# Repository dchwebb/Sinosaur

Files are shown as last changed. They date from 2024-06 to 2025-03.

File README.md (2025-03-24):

# Sinosaur

## Overview

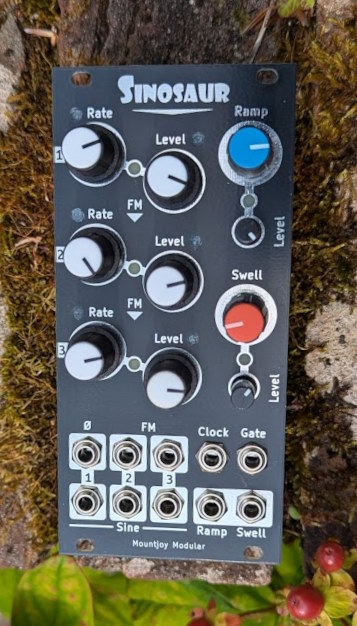
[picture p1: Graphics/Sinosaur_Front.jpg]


Sinosaur is an LFO and simple envelope generator for use in a Eurorack modular synthesiser. Two envelopes are available: a ramp and a swell, each with a speed and a level control. Each of the sine waves has a rate and level control both of which can be controlled with either envelope.

Sine 1 has a normal output and a phase inverted output. Sines 2 and 3 have a normal output and an FM output, which is derived from the preceding sine wave. Clicking the sine wave's rate or level potentiometer switches the ramp or swell envelopes on for that control. An LED cycles between blue (ramp control), red (swell control) or off to show envelope control.

If a sine's rate is controlled by the ramp, then the rate of the sine wave will increase from its slowest rate up to the rate selected by the potentiometer. In swell mode the rate will increase to the potentiometer level and then fade back to its slowest rate. Envelope control over the sine wave's level works similarly.

A gate input controls the start of the ramp and swell envelopes. The ramp will increase to its selected level whilst the gate is high and then rapidly decrease to zero. The swell rise and fall times are jointly set by the swell potentiometer, with the fall time twice as slow as the rise time.

A clock input is also available to limit the sine wave rates to multiples and divisions of the clock. Changing the rate (either with the potentiometer or envelope) selects from 8x, 4x, 2x, 1, 0.5x and 0.25x the clock rate.

## Outputs

Outputs range from 0V to 6.6V. The level control of the sine waves amplifies from 0v up to a 0V - 6.6V level (ie unipolar rather than bipolar around a central level). The inverted sine's level is 6.6V when the level control is at zero and increases to a maximum swing of 6.6V to 0V.

The levels of the envlopes and sine waves is displayed using LEDs (blue for ramp, orange for swell and white for sine waves).

## Technical

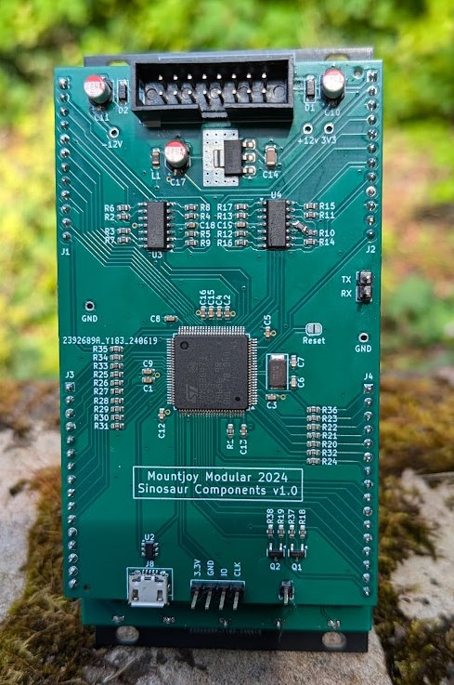
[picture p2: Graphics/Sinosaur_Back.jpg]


The module is based around an STM32G473 microcontroller, clocked at 170MHz. The various sine wave and envelopes are all generated internally by one of the microcontroller's seven 12 bit DACs.

TL074 quad op-amps are used to amplify (and/or phase invert) the outputs from 3.3V to 6.6V at maximum.

The level LEDs are controlled by PWM by hardware Timer channels on the microcontroller. Clock and Gate inputs are protected with transistor voltage limiters.

The module is designed to support USB input but this is unused at present.

[Components schematic](Hardware/Sinosaur_Components.pdf)

[Controls schematic](Hardware/Sinosaur_Controls.pdf)

## Power

Power is supplied via a 3.3V LDO regulator.

- +12V current draw: 90 mA
- -12V Current draw: 14 mA

## Errata

The inverted output of sine 1 will produce a -6.6V to 0V signal. As detailed on the component schematic a resistor is added to mix in the -12V signal raising the output to 0 - 6.6N.

This is still not ideal as at a zero level the inverted output is at 6.6V. No obvious solution available other than adding an additional DAC.

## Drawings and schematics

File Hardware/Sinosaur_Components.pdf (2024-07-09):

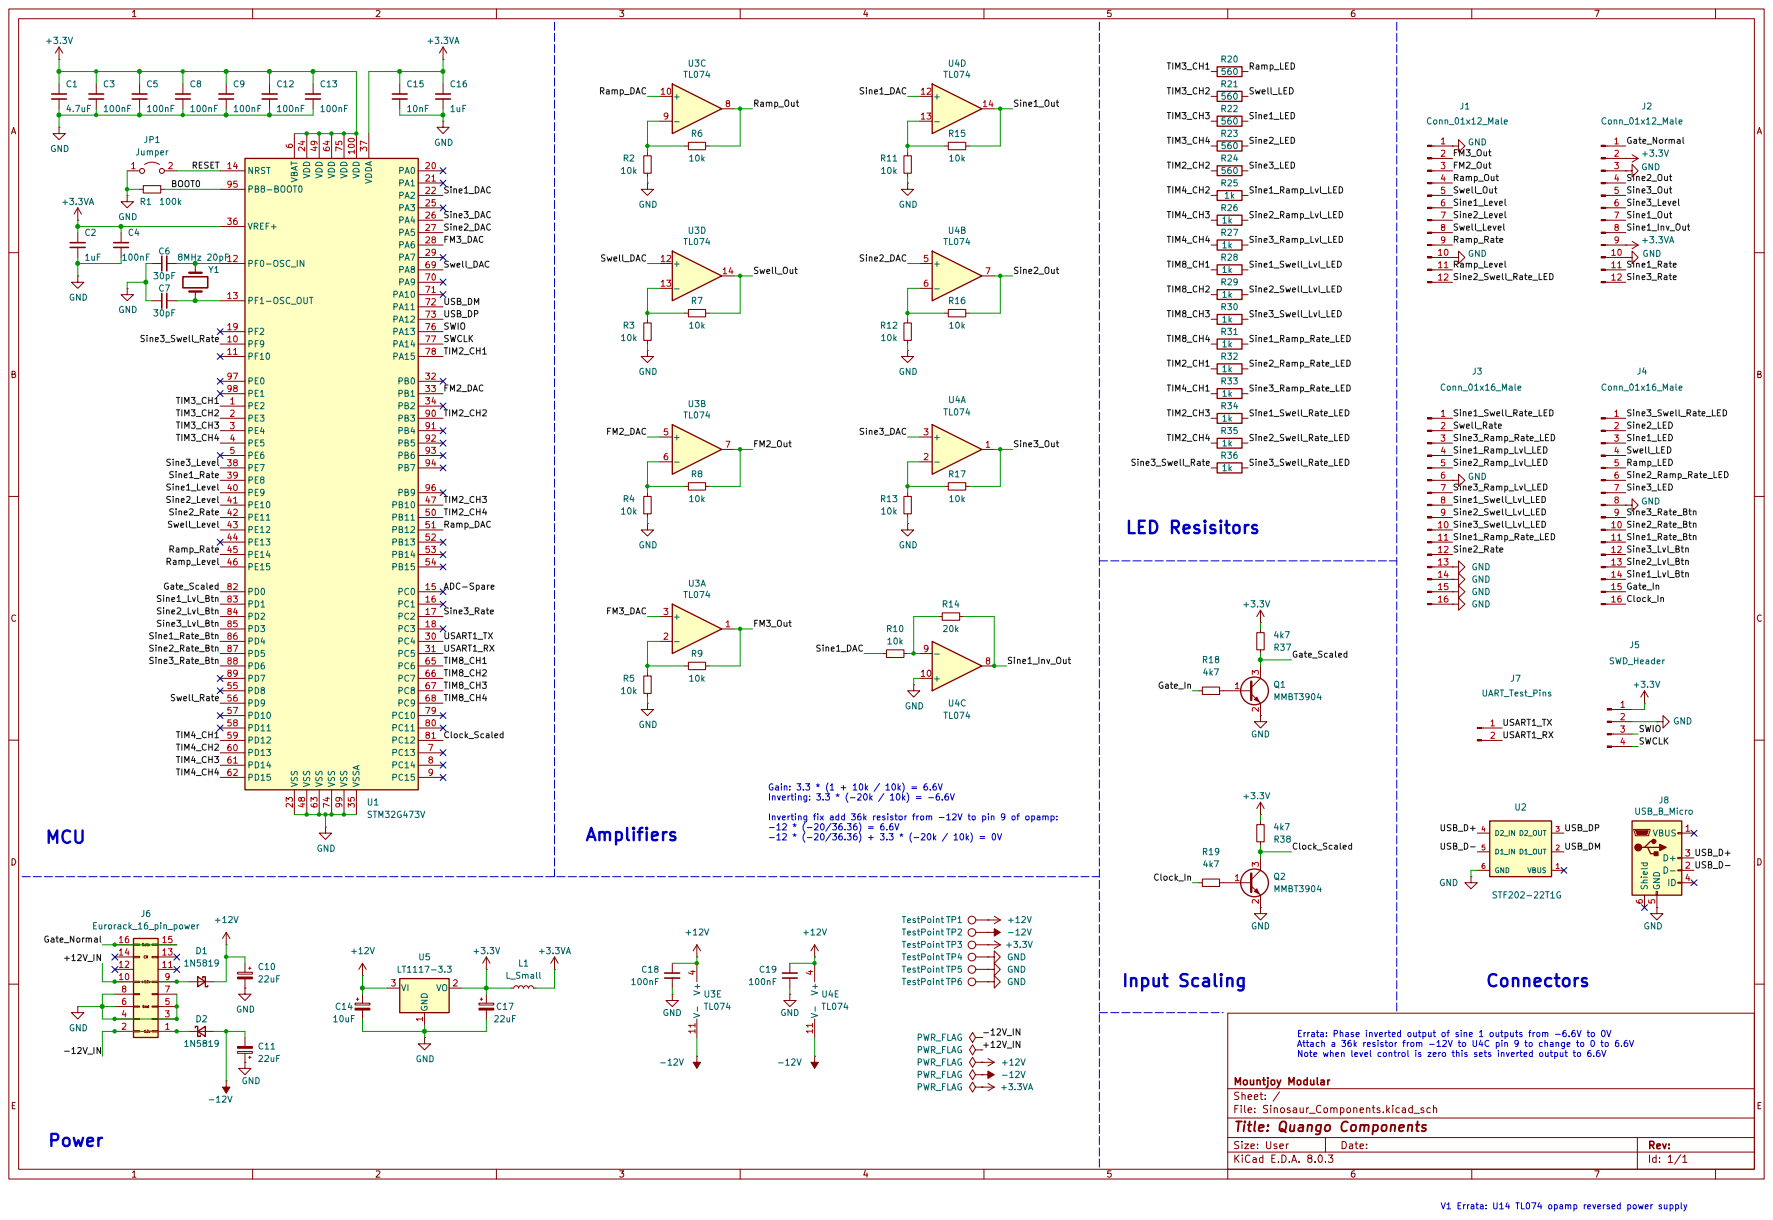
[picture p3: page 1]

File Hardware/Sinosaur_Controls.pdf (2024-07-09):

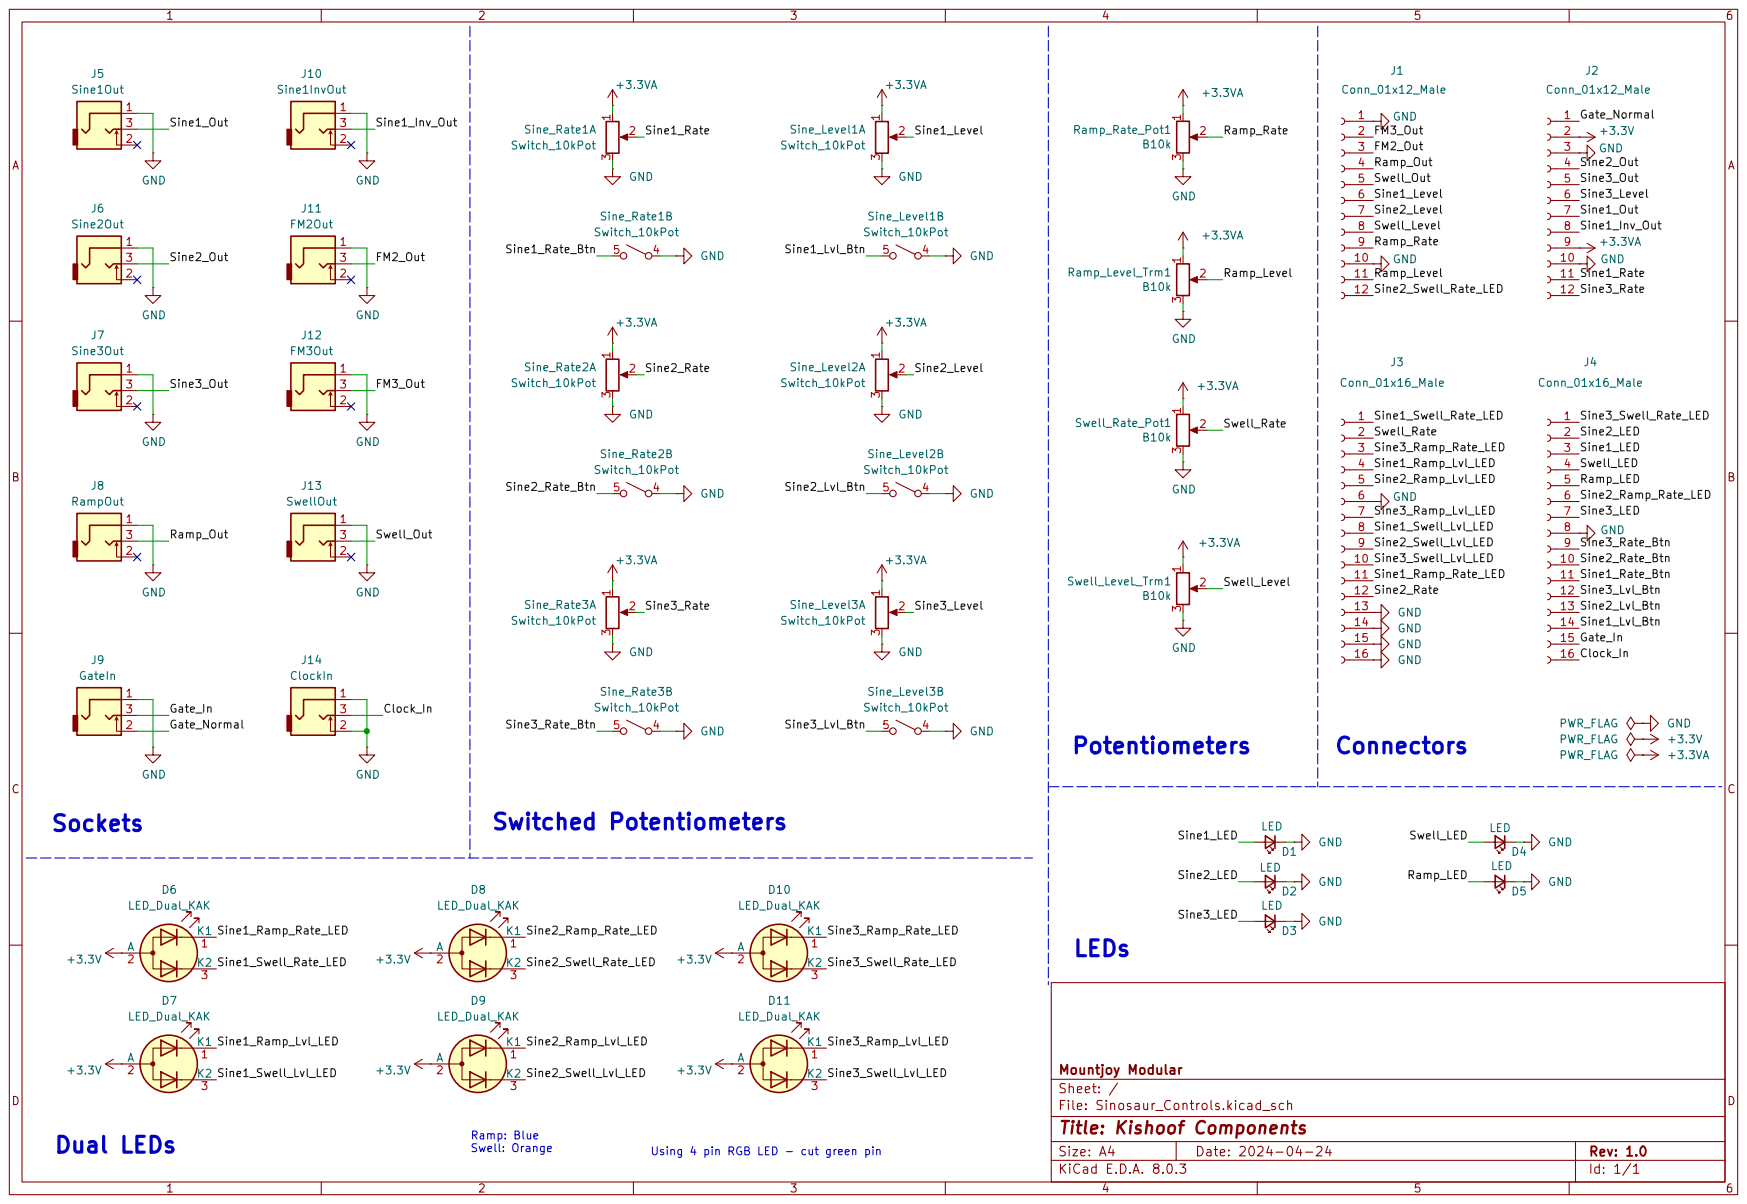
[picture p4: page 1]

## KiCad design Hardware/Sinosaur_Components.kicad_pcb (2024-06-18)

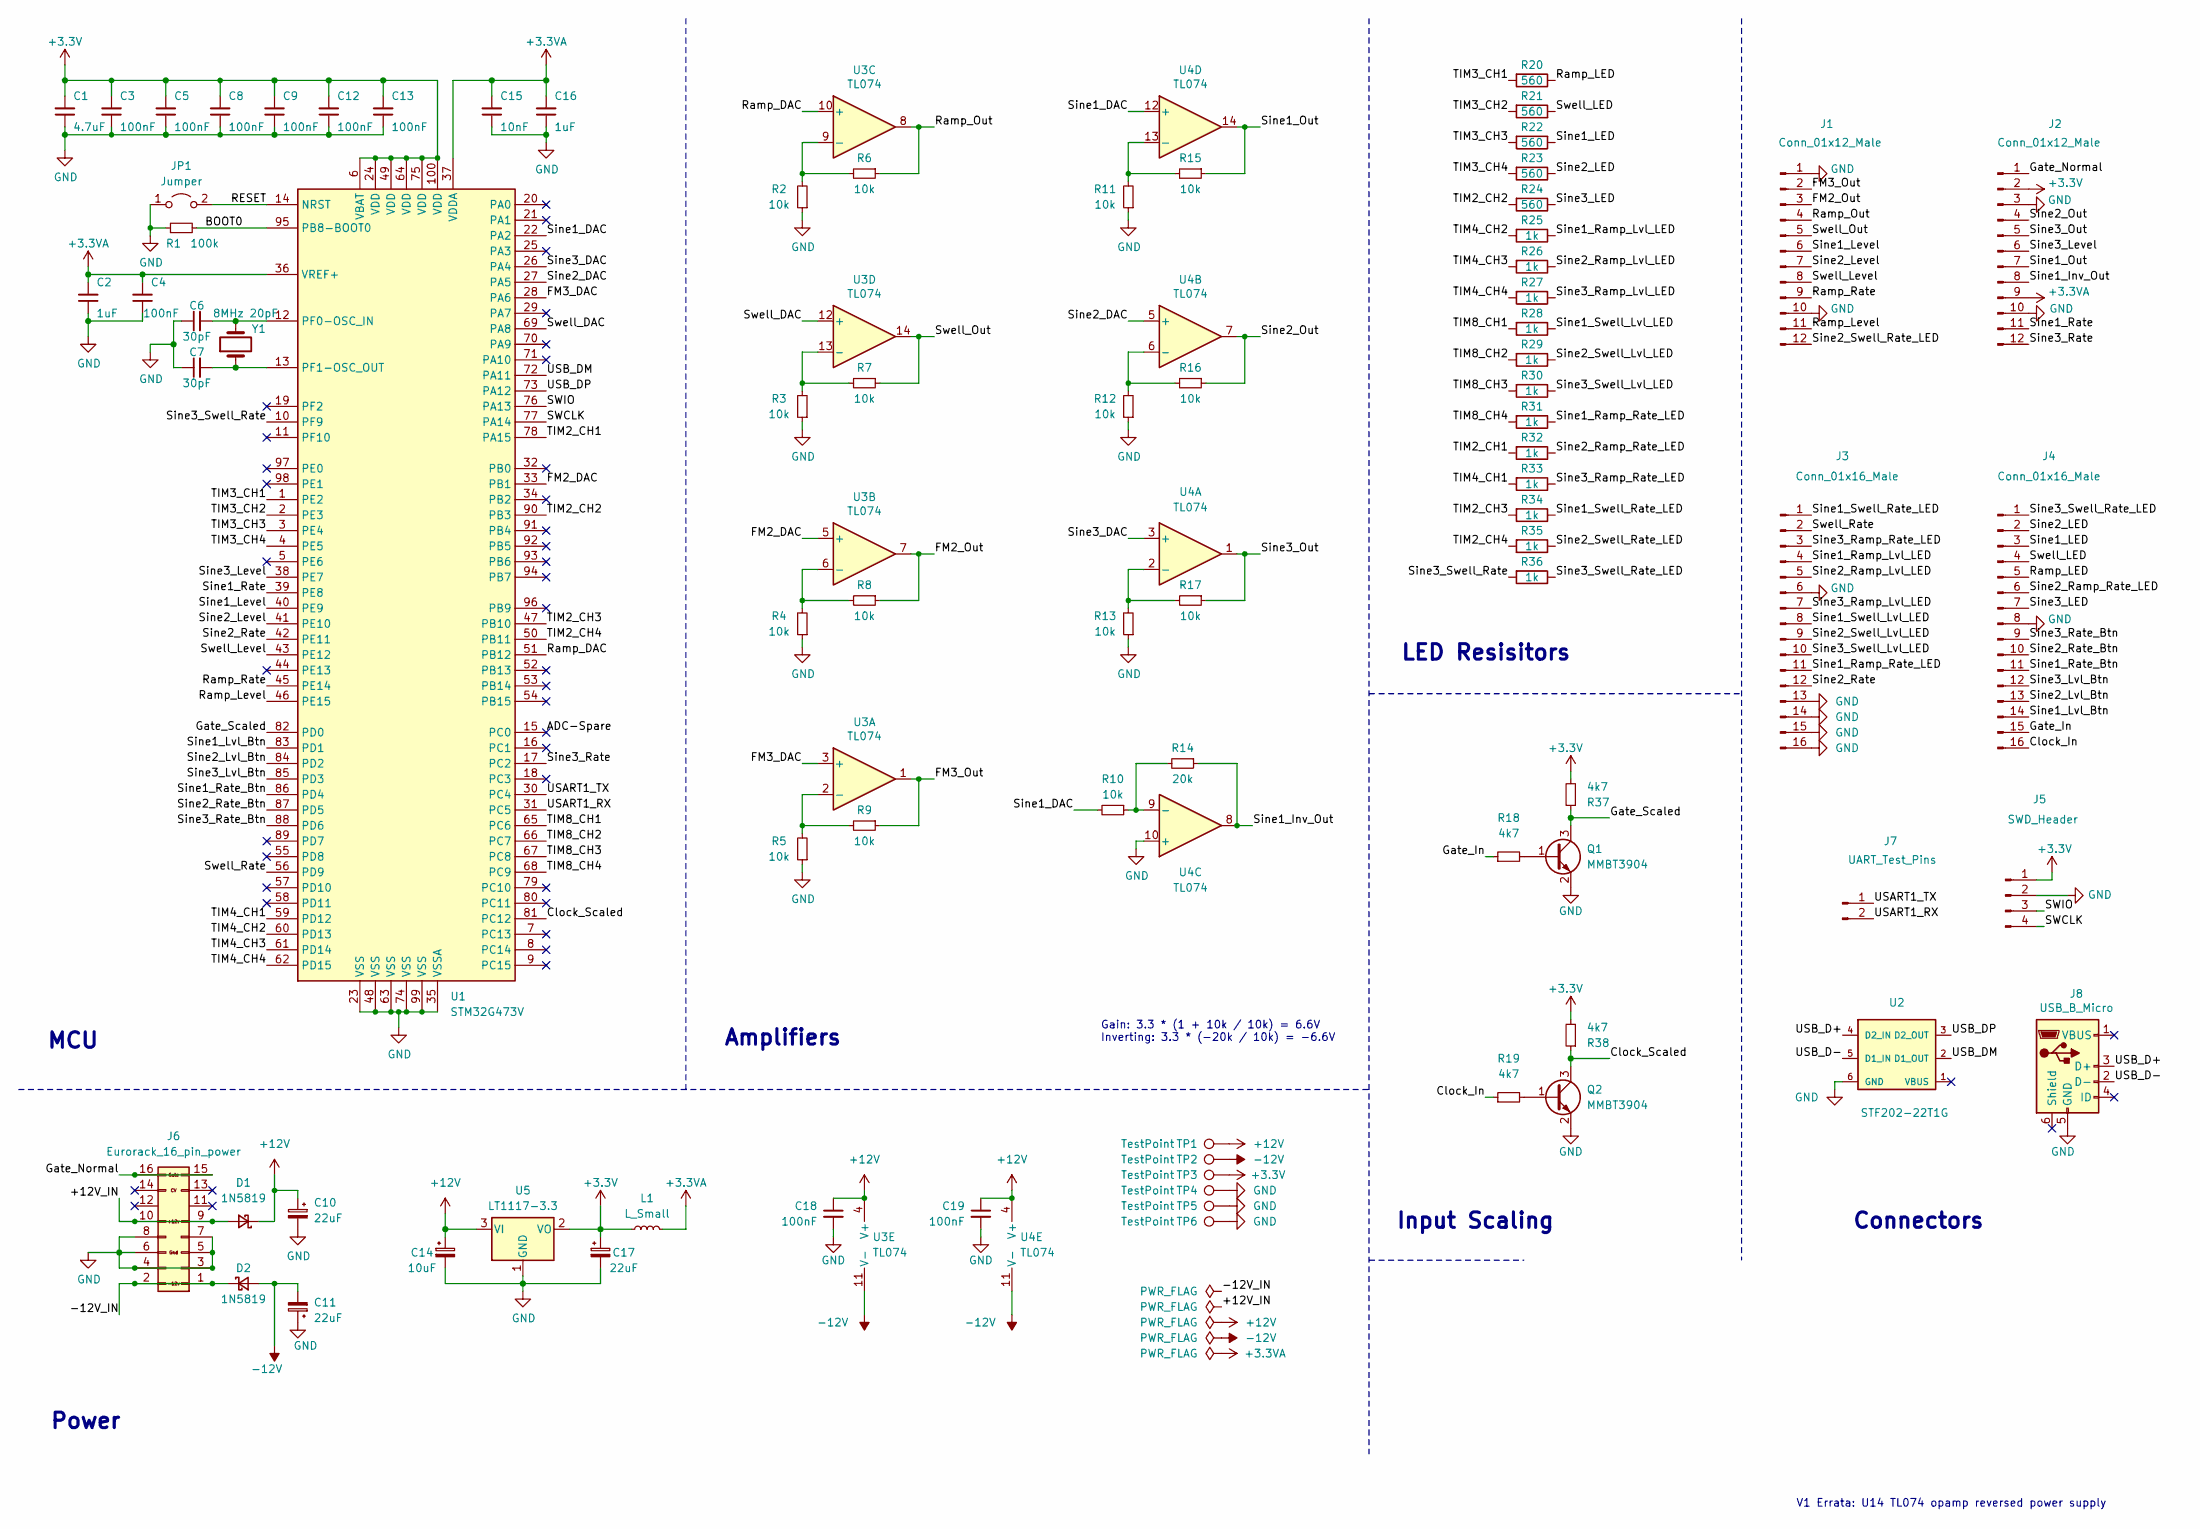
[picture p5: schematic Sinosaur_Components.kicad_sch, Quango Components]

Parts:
C1: 4.7uF; C_0603_1608Metric; Part_Number C19666
C2, C16: 1uF; C_0603_1608Metric; Part_Number C15849
C3, C4, C5, C8, C9, C12, C13: 100nF; C_0603_1608Metric; Part_Number C14663
C6, C7: 30pF; C_0603_1608Metric; Part_Number C22397
C10, C11, C17: 22uF; CP_Elec_4x5.8
C14: 10uF; C_1206_3216Metric
C15: 10nF; C_0603_1608Metric; Part_Number C57112
C18, C19: 100nF; C_0603_1608Metric; Part_Number C23630
D1, D2: 1N5819; D_SOD-123
J1, J2: Conn_01x12_Male; PinHeader_1x12_P2.54mm_Vertical
J3, J4: Conn_01x16_Male; PinHeader_1x16_P2.54mm_Vertical
J5: SWD_Header; SWD_header
J6: Eurorack_16_pin_power; Eurorack_16_pin_header
J7: UART_Test_Pins; PinHeader_1x02_P2.54mm_Vertical
J8: USB_B_Micro; USB_Micro-B_Amphenol
JP1: Jumper; SolderJumper-2_P1.3mm_Open_RoundedPad1.0x1.5mm
L1: L_Small; L_0805_2012Metric_Pad1.05x1.20mm_HandSolder; Part_Number C1046
Q1, Q2: MMBT3904; SOT-23; Part_Number C20526
R1: 100k; R_0603_1608Metric; Part_Number C25803
R2, R3, R4, R5, R6, R7, R8, R9, R10, R11, R12, R13, R15, R16, R17: 10k; R_0603_1608Metric
R14: 20k; R_0603_1608Metric
R18, R19, R37, R38: 4k7; R_0603_1608Metric; Part_Number C23162
R20, R21, R22, R23, R24: 560; R_0603_1608Metric; Part_Number C23212
R25, R26, R27, R28, R29, R30, R31, R32, R33, R34, R35, R36: 1k; R_0603_1608Metric; Part_Number C23212
TP1, TP2, TP3, TP4, TP5, TP6: TestPoint; 1mm_Test_Point
U1: STM32G473V; LQFP-100_14x14mm_P0.5mm
U2: STF202-22T1G
U3, U4: TL074; SOIC-14_3.9x8.7mm_P1.27mm
U5: LT1117-3.3; SOT-223-3_TabPin2
Y1: 8MHz 20pF; Crystal_SMD_0603-2Pin_6.0x3.5mm; Part_Number C115962

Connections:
+3.3V: C1.2, C3.2, C5.2, C8.2, C9.2, C12.2, C13.2, C17.1, J2.2, J5.1, L1.1, R37.2, R38.2, TP3.1, U1.6 (VBAT), U1.24 (VDD), U1.49 (VDD), U1.64 (VDD), U1.75 (VDD), U1.100 (VDD), U5.2 (VO)
+3.3VA: C2.2, C4.2, C15.2, C16.2, J2.9, L1.2, U1.36 (VREF+), U1.37 (VDDA)
+12V: C10.1, C14.1, C18.1, C19.1, D1.1 (K), TP1.1, U3.4 (V+), U4.4 (V+), U5.3 (VI)
-12V: C11.2, D2.2 (A), TP2.1, U3.11 (V-), U4.11 (V-)
/+12V_IN: D1.2 (A), J6.9, J6.10
/-12V_IN: D2.1 (K), J6.1, J6.2
/ADC-Spare: U1.15 (PC0)
/BOOT0: R1.2, U1.95 (PB8-BOOT0)
/Clock_In: J4.16, R19.1
/Clock_Scaled: Q2.3 (C), R38.1, U1.81 (PC12)
/FM2_DAC: U1.33 (PB1), U3.5 (+)
/FM2_Out: J1.3, R8.1, U3.7
/FM3_DAC: U1.28 (PA6), U3.3 (+)
/FM3_Out: J1.2, R9.1, U3.1
/Gate_In: J4.15, R18.1
/Gate_Normal: J2.1, J6.15, J6.16
/Gate_Scaled: Q1.3 (C), R37.1, U1.82 (PD0)
/RESET: JP1.2 (B), U1.14 (NRST)
/Ramp_DAC: U1.51 (PB12), U3.10 (+)
/Ramp_LED: J4.5, R20.1
/Ramp_Level: J1.11, U1.46 (PE15)
/Ramp_Out: J1.4, R6.1, U3.8
/Ramp_Rate: J1.9, U1.45 (PE14)
/SWCLK: J5.4, U1.77 (PA14)
/SWIO: J5.3, U1.76 (PA13)
/Sine1_DAC: R10.2, U1.22 (PA2), U4.12 (+)
/Sine1_Inv_Out: J2.8, R14.1, U4.8
/Sine1_LED: J4.3, R22.1
/Sine1_Level: J1.6, U1.40 (PE9)
/Sine1_Lvl_Btn: J4.14, U1.83 (PD1)
/Sine1_Out: J2.7, R15.1, U4.14
/Sine1_Ramp_Lvl_LED: J3.4, R25.1
/Sine1_Ramp_Rate_LED: J3.11, R31.1
/Sine1_Rate: J2.11, U1.39 (PE8)
/Sine1_Rate_Btn: J4.11, U1.86 (PD4)
/Sine1_Swell_Lvl_LED: J3.8, R28.1
/Sine1_Swell_Rate_LED: J3.1, R34.1
/Sine2_DAC: U1.27 (PA5), U4.5 (+)
/Sine2_LED: J4.2, R23.1
/Sine2_Level: J1.7, U1.41 (PE10)
/Sine2_Lvl_Btn: J4.13, U1.84 (PD2)
/Sine2_Out: J2.4, R16.1, U4.7
/Sine2_Ramp_Lvl_LED: J3.5, R26.1
/Sine2_Ramp_Rate_LED: J4.6, R32.1
/Sine2_Rate: J3.12, U1.42 (PE11)
/Sine2_Rate_Btn: J4.10, U1.87 (PD5)
/Sine2_Swell_Lvl_LED: J3.9, R29.1
/Sine2_Swell_Rate_LED: J1.12, R35.1
/Sine3_DAC: U1.26 (PA4), U4.3 (+)
/Sine3_LED: J4.7, R24.1
/Sine3_Level: J2.6, U1.38 (PE7)
/Sine3_Lvl_Btn: J4.12, U1.85 (PD3)
/Sine3_Out: J2.5, R17.1, U4.1
/Sine3_Ramp_Lvl_LED: J3.7, R27.1
/Sine3_Ramp_Rate_LED: J3.3, R33.1
/Sine3_Rate: J2.12, U1.17 (PC2)
/Sine3_Rate_Btn: J4.9, U1.88 (PD6)
/Sine3_Swell_Lvl_LED: J3.10, R30.1
/Sine3_Swell_Rate: R36.2, U1.10 (PF9)
/Sine3_Swell_Rate_LED: J4.1, R36.1
/Swell_DAC: U1.69 (PA8), U3.12 (+)
/Swell_LED: J4.4, R21.1
/Swell_Level: J1.8, U1.43 (PE12)
/Swell_Out: J1.5, R7.1, U3.14
/Swell_Rate: J3.2, U1.56 (PD9)
/TIM2_CH1: R32.2, U1.78 (PA15)
/TIM2_CH2: R24.2, U1.90 (PB3)
/TIM2_CH3: R34.2, U1.47 (PB10)
/TIM2_CH4: R35.2, U1.50 (PB11)
/TIM3_CH1: R20.2, U1.1 (PE2)
/TIM3_CH2: R21.2, U1.2 (PE3)
/TIM3_CH3: R22.2, U1.3 (PE4)
/TIM3_CH4: R23.2, U1.4 (PE5)
/TIM4_CH1: R33.2, U1.59 (PD12)
/TIM4_CH2: R25.2, U1.60 (PD13)
/TIM4_CH3: R26.2, U1.61 (PD14)
/TIM4_CH4: R27.2, U1.62 (PD15)
/TIM8_CH1: R28.2, U1.65 (PC6)
/TIM8_CH2: R29.2, U1.66 (PC7)
/TIM8_CH3: R30.2, U1.67 (PC8)
/TIM8_CH4: R31.2, U1.68 (PC9)
/USART1_RX: J7.2, U1.31 (PC5)
/USART1_TX: J7.1, U1.30 (PC4)
/USB_D+: J8.3 (D+), U2.4 (D2_IN)
/USB_D-: J8.2 (D-), U2.5 (D1_IN)
/USB_DM: U1.72 (PA11), U2.2 (D1_OUT)
/USB_DP: U1.73 (PA12), U2.3 (D2_OUT)
GND: C1.1, C2.1, C3.1, C4.1, C5.1, C6.1, C7.1, C8.1, C9.1, C10.2, C11.1, C12.1, C13.1, C14.2, C15.1, C16.1, C17.2, C18.2, C19.2, J1.1, J1.10, J2.3, J2.10, J3.6, J3.13, J3.14, J3.15, J3.16, J4.8, J5.2, J6.3, J6.4, J6.5, J6.6, J6.7, J6.8, J8.5 (GND), JP1.1 (A), Q1.2 (E), Q2.2 (E), R1.1, R2.1, R3.1, R4.1, R5.1, R11.1, R12.1, R13.1, TP4.1, TP5.1, TP6.1, U1.23 (VSS), U1.35 (VSSA), U1.48 (VSS), U1.63 (VSS), U1.74 (VSS), U1.99 (VSS), U2.6 (GND), U4.10 (+), U5.1 (GND)
unnamed: Q1.1 (B), R18.2
unnamed: Q2.1 (B), R19.2
unnamed: C6.2, U1.12 (PF0-OSC_IN), Y1.2
unnamed: C7.2, U1.13 (PF1-OSC_OUT), Y1.1
unnamed: R5.2, R9.2, U3.2 (-)
unnamed: R4.2, R8.2, U3.6 (-)
unnamed: R2.2, R6.2, U3.9 (-)
unnamed: R3.2, R7.2, U3.13 (-)
unnamed: R13.2, R17.2, U4.2 (-)
unnamed: R12.2, R16.2, U4.6 (-)
unnamed: R10.1, R14.2, U4.9 (-)
unnamed: R11.2, R15.2, U4.13 (-)

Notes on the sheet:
Connectors
Power
V1 Errata: U14 TL074 opamp reversed power supply
MCU
Gain: 3.3 * (1 + 10k / 10k) = 6.6V Inverting: 3.3 * (-20k / 10k) = -6.6V
Input Scaling
Amplifiers
LED Resisitors

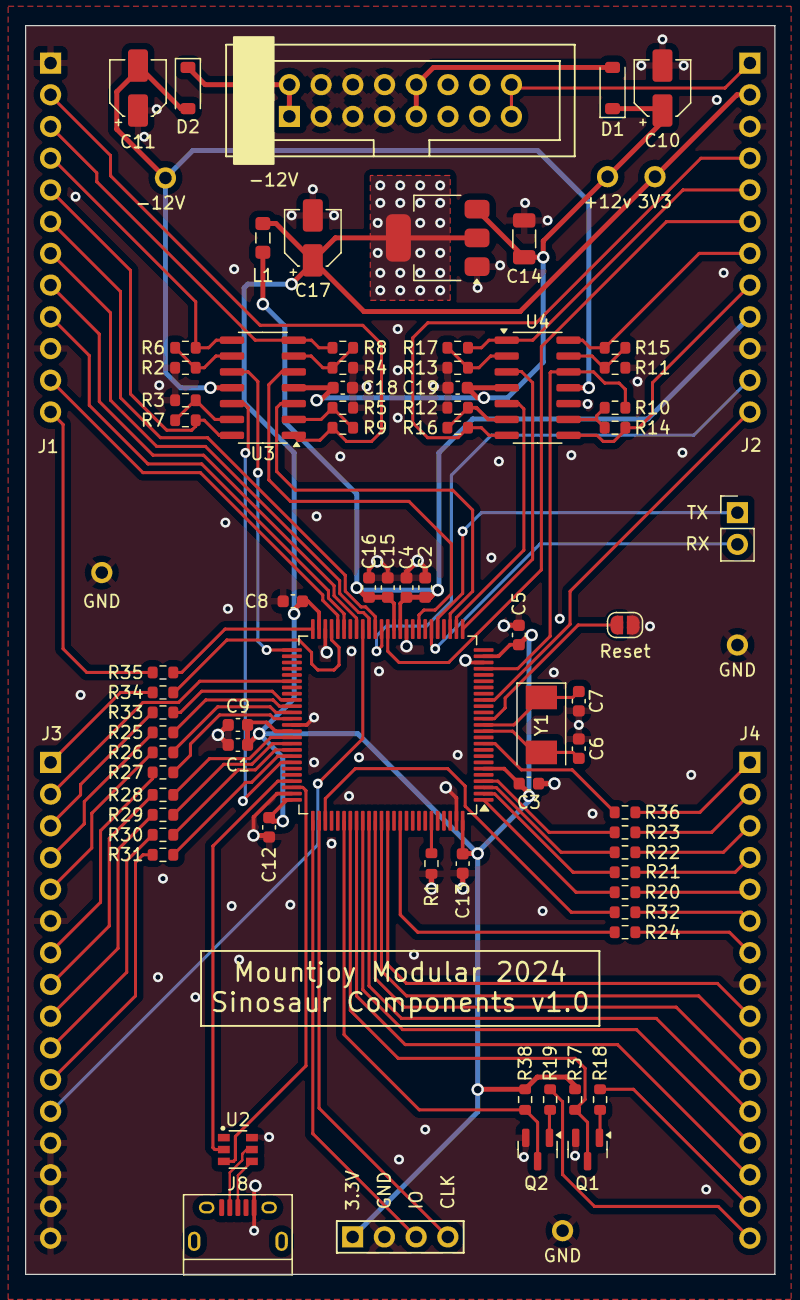
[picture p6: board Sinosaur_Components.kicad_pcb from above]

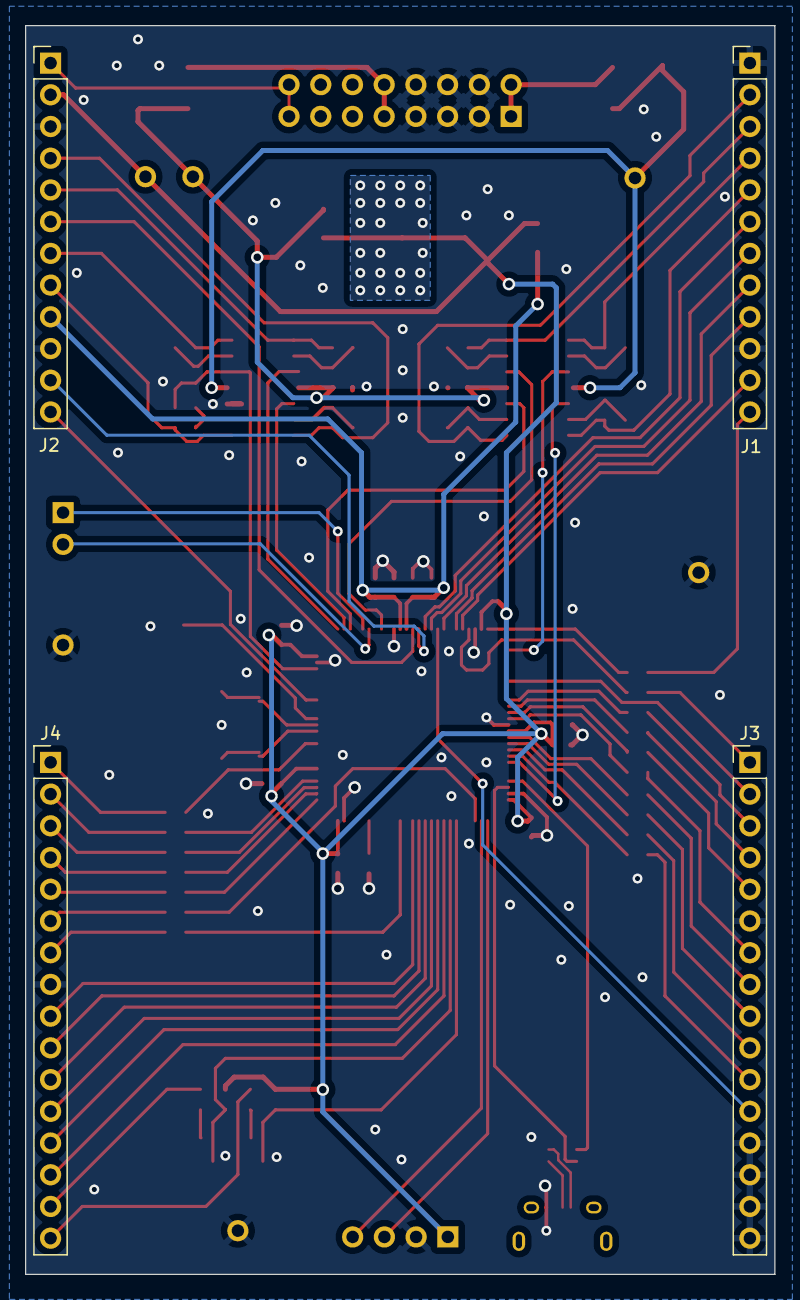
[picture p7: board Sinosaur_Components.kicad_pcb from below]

Board: 4 copper layers, 60.0 x 100.0 mm, 83 parts (4 on the bottom side), 99 nets.

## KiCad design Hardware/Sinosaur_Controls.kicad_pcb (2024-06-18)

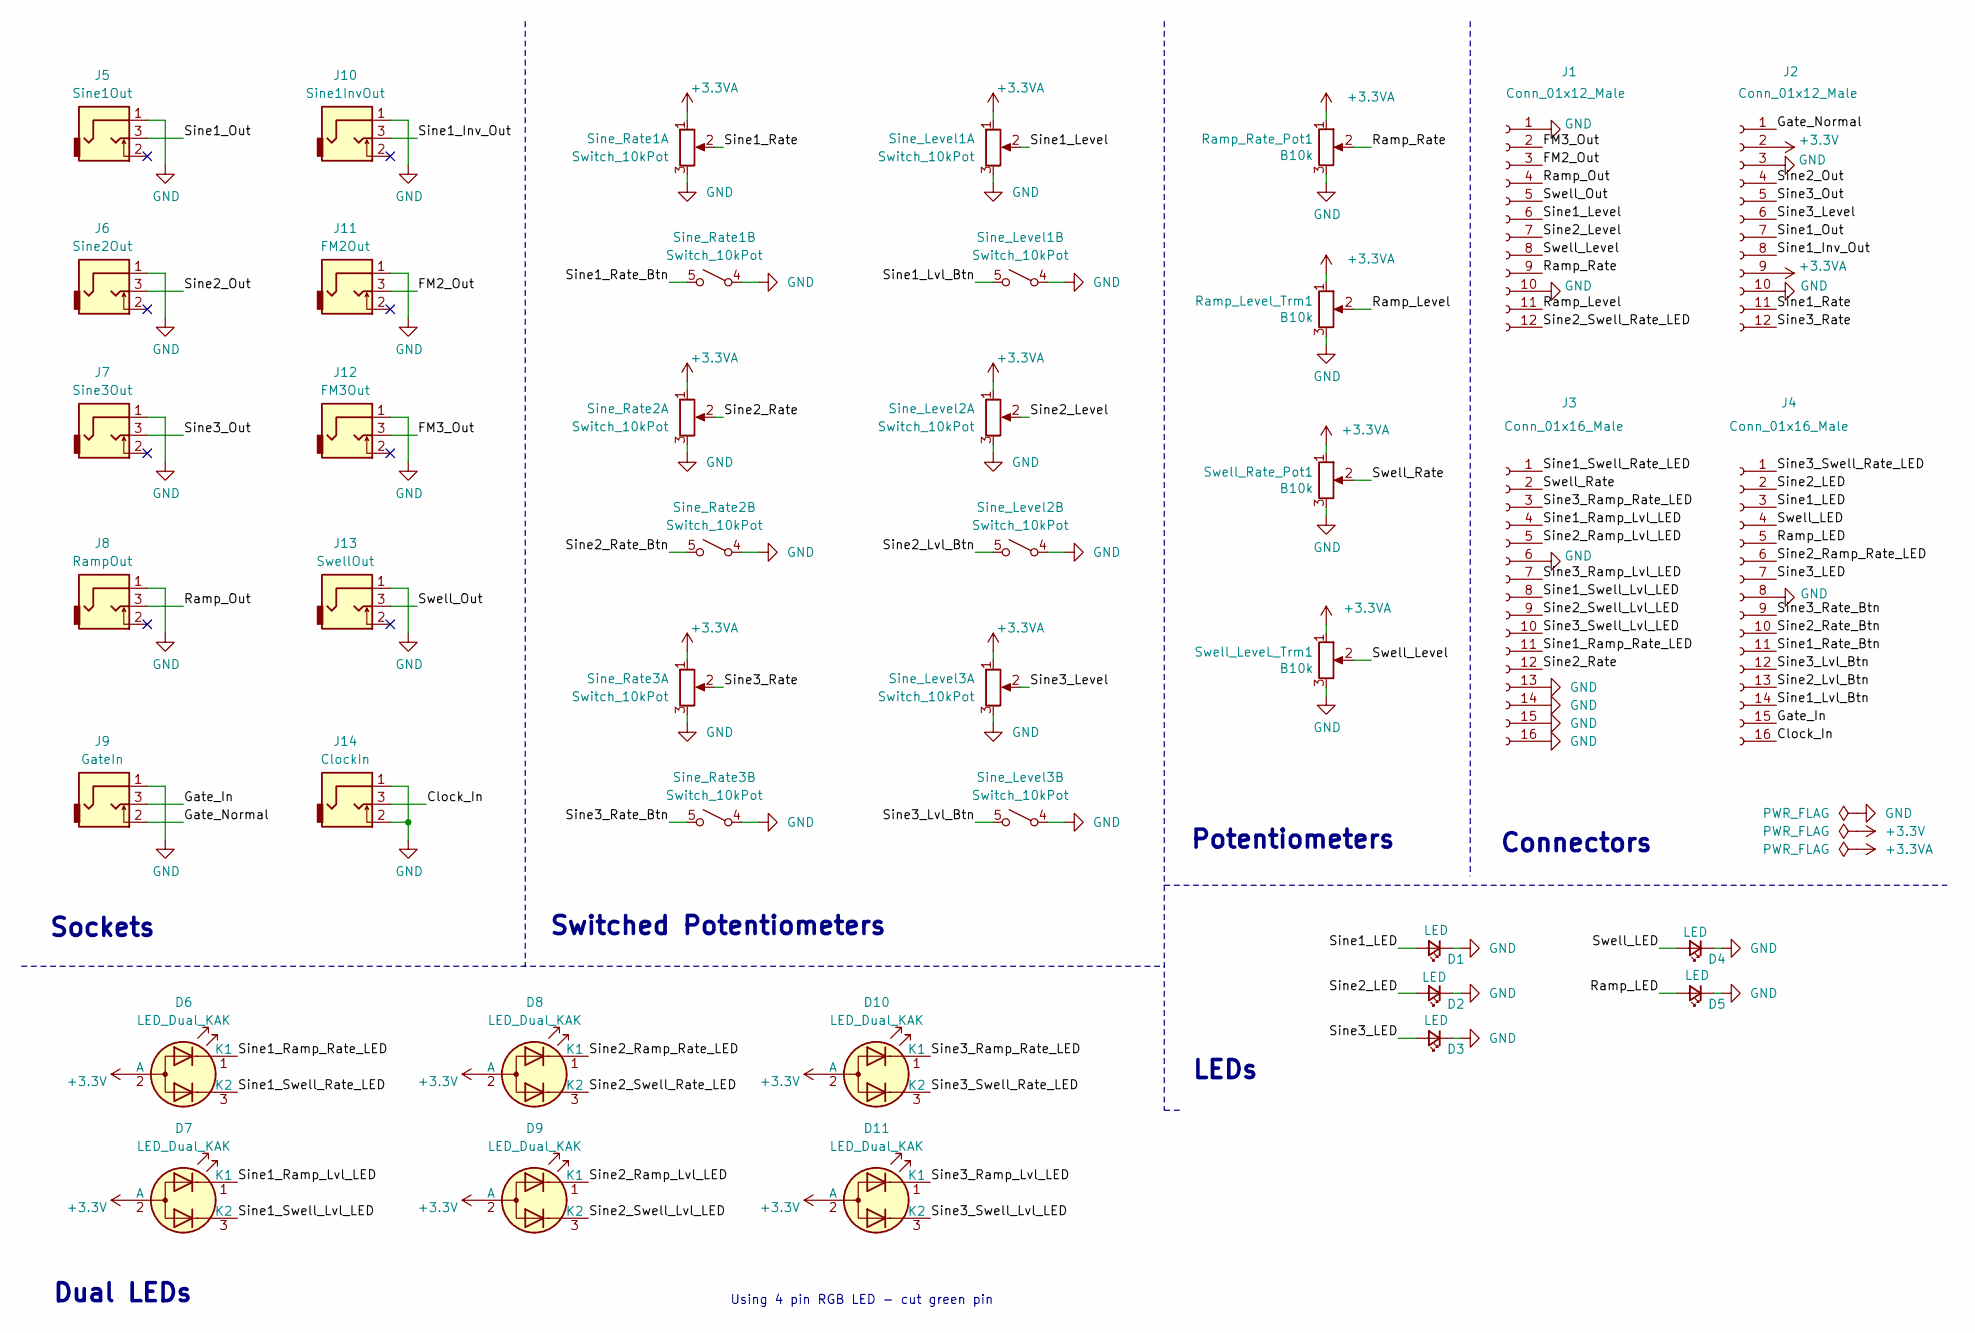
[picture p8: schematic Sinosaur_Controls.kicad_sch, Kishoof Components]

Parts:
D1, D2, D3, D4, D5: LED; LED_D3.0mm
D6, D7, D8, D9, D10, D11: LED_Dual_KAK; LED_D3.0mm-3
J1, J2: Conn_01x12_Male; PinSocket_1x12_P2.54mm_Vertical
J3, J4: Conn_01x16_Male; PinSocket_1x16_P2.54mm_Vertical
J5: Sine1Out; THONKICONN_hole
J6: Sine2Out; THONKICONN_hole
J7: Sine3Out; THONKICONN_hole
J8: RampOut; THONKICONN_hole
J9: GateIn; THONKICONN_hole
J10: Sine1InvOut; THONKICONN_hole
J11: FM2Out; THONKICONN_hole
J12: FM3Out; THONKICONN_hole
J13: SwellOut; THONKICONN_hole
J14: ClockIn; THONKICONN_hole
Ramp_Level_Trm1: B10k; Alpha_9mm_Potentiometer_Aligned
Ramp_Rate_Pot1: B10k; Alpha_9mm_Potentiometer_Aligned
Sine_Level1, Sine_Level2, Sine_Level3: Switch_10kPot; Bourns_Switch_Potentiometer
Sine_Rate1, Sine_Rate2, Sine_Rate3: Switch_10kPot; Bourns_Switch_Potentiometer
Swell_LeveL_Trm1: B10k; Alpha_9mm_Potentiometer_Aligned
Swell_Rate_Pot1: B10k; Alpha_9mm_Potentiometer_Aligned

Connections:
+3.3V: D6.2 (A), D7.2 (A), D8.2 (A), D9.2 (A), D10.2 (A), D11.2 (A), J2.2
+3.3VA: J2.9, Ramp_Level_Trm1.1, Ramp_Rate_Pot1.1, Sine_Level1.1, Sine_Level2.1, Sine_Level3.1, Sine_Rate1.1, Sine_Rate2.1, Sine_Rate3.1, Swell_LeveL_Trm1.1, Swell_Rate_Pot1.1
/Clock_In: J4.16, J14.3
/FM2_Out: J1.3, J11.3
/FM3_Out: J1.2, J12.3
/Gate_In: J4.15, J9.3
/Gate_Normal: J2.1, J9.2
/Ramp_LED: D5.2 (A), J4.5
/Ramp_Level: J1.11, Ramp_Level_Trm1.2
/Ramp_Out: J1.4, J8.3
/Ramp_Rate: J1.9, Ramp_Rate_Pot1.2
/Sine1_Inv_Out: J2.8, J10.3
/Sine1_LED: D1.2 (A), J4.3
/Sine1_Level: J1.6, Sine_Level1.2
/Sine1_Lvl_Btn: J4.14, Sine_Level1.5 (2)
/Sine1_Out: J2.7, J5.3
/Sine1_Ramp_Lvl_LED: D7.1 (K1), J3.4
/Sine1_Ramp_Rate_LED: D6.1 (K1), J3.11
/Sine1_Rate: J2.11, Sine_Rate1.2
/Sine1_Rate_Btn: J4.11, Sine_Rate1.5 (2)
/Sine1_Swell_Lvl_LED: D7.3 (K2), J3.8
/Sine1_Swell_Rate_LED: D6.3 (K2), J3.1
/Sine2_LED: D2.2 (A), J4.2
/Sine2_Level: J1.7, Sine_Level2.2
/Sine2_Lvl_Btn: J4.13, Sine_Level2.5 (2)
/Sine2_Out: J2.4, J6.3
/Sine2_Ramp_Lvl_LED: D9.1 (K1), J3.5
/Sine2_Ramp_Rate_LED: D8.1 (K1), J4.6
/Sine2_Rate: J3.12, Sine_Rate2.2
/Sine2_Rate_Btn: J4.10, Sine_Rate2.5 (2)
/Sine2_Swell_Lvl_LED: D9.3 (K2), J3.9
/Sine2_Swell_Rate_LED: D8.3 (K2), J1.12
/Sine3_LED: D3.2 (A), J4.7
/Sine3_Level: J2.6, Sine_Level3.2
/Sine3_Lvl_Btn: J4.12, Sine_Level3.5 (2)
/Sine3_Out: J2.5, J7.3
/Sine3_Ramp_Lvl_LED: D11.1 (K1), J3.7
/Sine3_Ramp_Rate_LED: D10.1 (K1), J3.3
/Sine3_Rate: J2.12, Sine_Rate3.2
/Sine3_Rate_Btn: J4.9, Sine_Rate3.5 (2)
/Sine3_Swell_Lvl_LED: D11.3 (K2), J3.10
/Sine3_Swell_Rate_LED: D10.3 (K2), J4.1
/Swell_LED: D4.2 (A), J4.4
/Swell_Level: J1.8, Swell_LeveL_Trm1.2
/Swell_Out: J1.5, J13.3
/Swell_Rate: J3.2, Swell_Rate_Pot1.2
GND: D1.1 (K), D2.1 (K), D3.1 (K), D4.1 (K), D5.1 (K), J1.1, J1.10, J2.3, J2.10, J3.6, J3.13, J3.14, J3.15, J3.16, J4.8, J5.1, J6.1, J7.1, J8.1, J9.1, J10.1, J11.1, J12.1, J13.1, J14.1, J14.2, Ramp_Level_Trm1.3, Ramp_Rate_Pot1.3, Sine_Level1.3, Sine_Level1.4 (1), Sine_Level2.3, Sine_Level2.4 (1), Sine_Level3.3, Sine_Level3.4 (1), Sine_Rate1.3, Sine_Rate1.4 (1), Sine_Rate2.3, Sine_Rate2.4 (1), Sine_Rate3.3, Sine_Rate3.4 (1), Swell_LeveL_Trm1.3, Swell_Rate_Pot1.3

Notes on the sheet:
Sockets
Dual LEDs
Using 4 pin RGB LED - cut green pin
Connectors
Switched Potentiometers
LEDs
Potentiometers

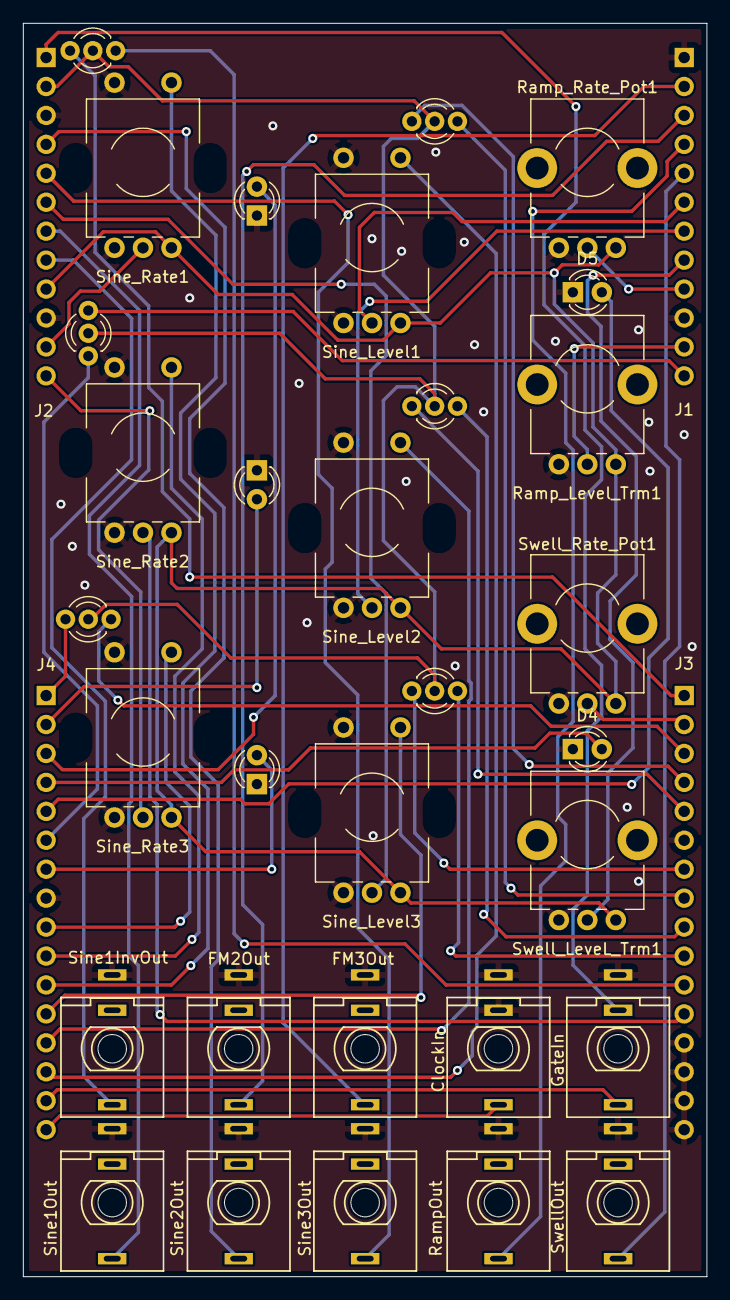
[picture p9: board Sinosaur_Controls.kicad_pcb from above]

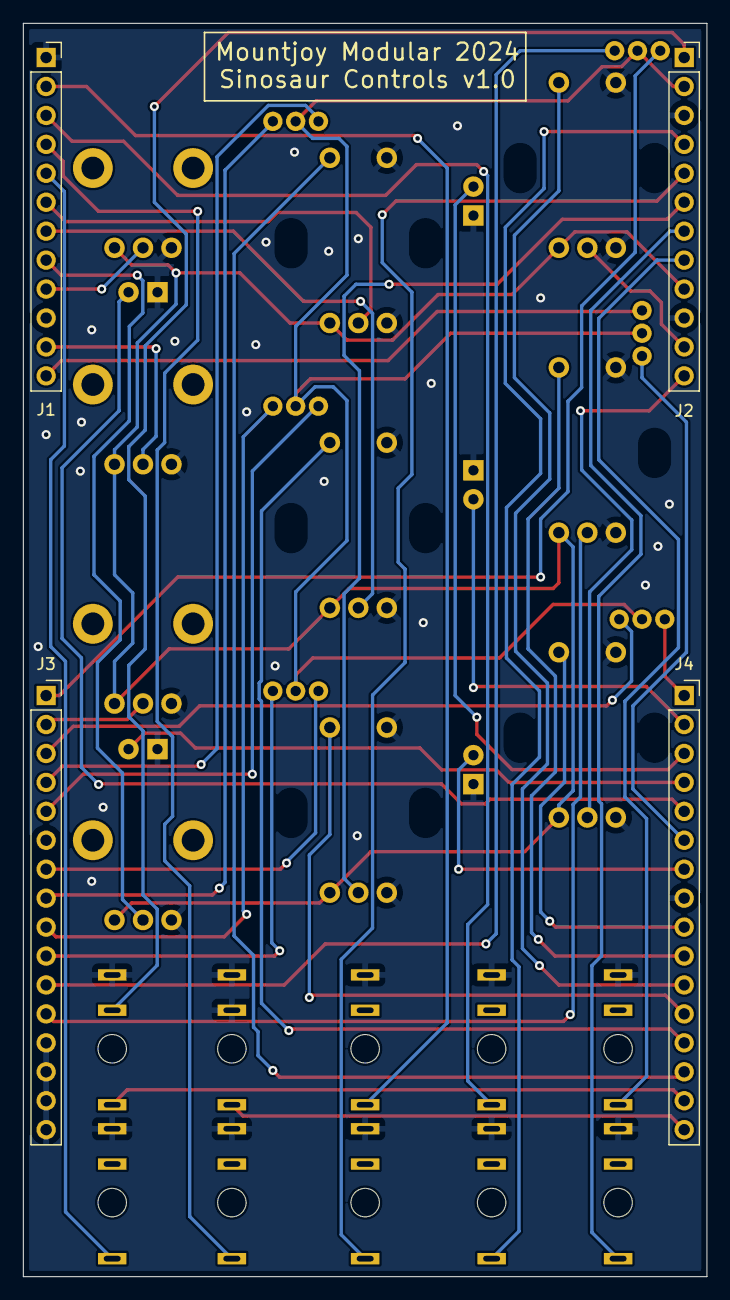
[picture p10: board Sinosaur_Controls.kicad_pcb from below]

Board: 2 copper layers, 60.0 x 110.0 mm, 35 parts (4 on the bottom side), 47 nets.

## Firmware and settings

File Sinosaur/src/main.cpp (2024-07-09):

#include "initialisation.h"
#include "Modulation.h"

volatile uint32_t SysTickVal;
volatile ADCValues adc;

Config config{&modulation.configSaver};		// Construct config handler with list of configSavers

extern "C" {
#include "interrupts.h"
}


extern uint32_t SystemCoreClock;
int main(void)
{
	SystemInit();						// Activates floating point coprocessor and resets clock
	InitClocks();						// Configure the clock and PLL
	InitHardware();
	config.RestoreConfig();
	modulation.Init();
	InitOutputTimer();

	while (1) {
		config.SaveConfig();			// Save any scheduled changes
	}
}

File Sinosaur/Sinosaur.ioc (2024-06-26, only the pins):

Mcu.UserName=STM32G473VCTx
PA11.Signal=USB_DM
PA12.Signal=USB_DP
PA13.Signal=SYS_JTMS-SWDIO
PA14.Signal=SYS_JTCK-SWCLK
PA15.Signal=S_TIM2_CH1
PA2.Signal=OPAMP1_VOUT
PA4.Signal=COMP_DAC11_group
PA5.Signal=COMP_DAC12_group
PA6.Signal=COMP_DAC21_group
PA8.Signal=OPAMP5_VOUT
PB1.Signal=OPAMP3_VOUT
PB10.Signal=S_TIM2_CH3
PB11.Signal=S_TIM2_CH4
PB12.Signal=OPAMP4_VOUT
PB3.Signal=S_TIM2_CH2
PB6.Signal=S_TIM4_CH1
PC12.Signal=GPXTI12
PC2.Signal=ADC1_IN8
PC4.Signal=USART1_TX
PC5.Signal=USART1_RX
PC6.Signal=S_TIM8_CH1
PC7.Signal=S_TIM8_CH2
PC8.Signal=S_TIM8_CH3
PC9.Signal=S_TIM8_CH4
PD0.Signal=GPXTI0
PD1.Signal=GPXTI1
PD13.Signal=S_TIM4_CH2
PD14.Signal=S_TIM4_CH3
PD15.Signal=S_TIM4_CH4
PD2.Signal=GPXTI2
PD3.Signal=GPXTI3
PD4.Signal=GPXTI4
PD5.Signal=GPXTI5
PD6.Signal=GPXTI6
PD9.Signal=ADC4_IN13
PE10.Signal=ADC3_IN14
PE11.Signal=ADC3_IN15
PE14.Signal=ADC4_IN1
PE15.Signal=ADC4_IN2
PE2.Signal=S_TIM3_CH1
PE3.Signal=S_TIM3_CH2
PE4.Signal=S_TIM3_CH3
PE5.Signal=S_TIM3_CH4
PE7.Signal=ADC3_IN4
PE8.Signal=ADC3_IN6
PE9.Signal=ADC3_IN2
PF0-OSC_IN.Signal=RCC_OSC_IN
PF1-OSC_OUT.Signal=RCC_OSC_OUT
PF9.Signal=GPXTI9

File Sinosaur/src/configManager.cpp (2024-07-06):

#include "configManager.h"
#include <cstring>
#include <cstdio>
#include <cmath>

bool Config::SaveConfig(const bool forceSave)
{
	bool result = true;
	if (forceSave || (scheduleSave && SysTickVal > saveBooked + 60000)) {			// 60 seconds between saves
		GpioPin::SetHigh(GPIOD, 5);
		scheduleSave = false;

		if (currentSettingsOffset == -1) {					// Default = -1 if not first set in RestoreConfig
			currentSettingsOffset = 0;
		} else {
			currentSettingsOffset += settingsSize;
			if ((uint32_t)currentSettingsOffset > flashPageSize - settingsSize) {
				// Check if another page is available for use
				for (auto& page : pages) {
					if (!page.dirty && page.page != currentPage) {
						if (++currentIndex > configPageCount) { 	// set new index, wrapping at count of allowed config pages
							currentIndex = 0;
						}
						currentPage = page.page;
						SetCurrentConfigAddr();
						currentSettingsOffset = 0;
						page.index = currentIndex;
						page.dirty = true;
						break;
					}
				}
				if (currentSettingsOffset != 0) {			// No free configurations slots found - abort save
					printf("Error saving config - no space\r\n");
					return false;
				}
			}
		}
		uint32_t* flashPos = flashConfigAddr + currentSettingsOffset / 4;


		uint8_t configBuffer[settingsSize];					// Will hold all the data to be written by config savers
		memcpy(configBuffer, ConfigHeader, 4);
		configBuffer[4] = currentIndex;						// Store the index of the config to identify the active page
		uint32_t configPos = headerSize;
		for (auto& saver : configSavers) {					// Add individual config settings to buffer after header
			memcpy(&configBuffer[configPos], saver->settingsAddress, saver->settingsSize);
			configPos += saver->settingsSize;
		}

		FlashUnlock();										// Unlock Flash memory for writing
		FLASH->SR = flashAllErrors;							// Clear error flags in Status Register
		result = FlashProgram(flashPos, reinterpret_cast<uint32_t*>(&configBuffer), settingsSize);
		FlashLock();										// Lock Flash

		if (result) {
			printf("Config Saved (%lu bytes at %#010lx)\r\n", settingsSize, (uint32_t)flashPos);
		} else {
			printf("Error saving config\r\n");
		}
		GpioPin::SetLow(GPIOD, 5);
	}
	return result;
}


void Config::RestoreConfig()
{
	// Initialise page array - used to manage which page contains current config, and which pages are available for writing when current page full
	for (uint32_t i = 0; i < configPageCount; ++i) {
		pages[i].page = flashConfigPage + i;
		uint32_t* const addr = flashConfigAddr + i * (flashPageSize / 4);

		// Check if page is dirty
		for (uint32_t w = 0; w < (flashPageSize / 4); ++w) {
			if (addr[w] != 0xFFFFFFFF) {
				pages[i].dirty = true;
				break;
			}
		}

		// Check if there is a config block at the start of the page and read the index number if so
		pages[i].index = (addr[0] == *(uint32_t*)ConfigHeader) ? (uint8_t)addr[1] : 255;
	}

	// Work out which is the active config page: will be the highest index from the bottom before the sequence jumps
	std::sort(pages.begin(), pages.end(), [](const CfgPage& l, const CfgPage& r) { return l.index < r.index; });
	uint32_t index = pages[0].index;
	if (index == 255) {
		currentPage = flashConfigPage;
		currentIndex = 0;					// Each page is assigned an index to determine which contains the latest config
	} else {
		currentPage = pages[0].page;
		for (uint32_t i = 1; i < configPageCount; ++i) {
			if (pages[i].index == index + 1) {
				++index;
				currentPage = pages[i].page;
			} else {
				break;
			}
		}
		currentIndex = index;
	}
	SetCurrentConfigAddr();				// Set the base address of the page holding the current config

	// Erase any dirty pages that are not the current one, or do not contain config data
	for (auto& page : pages) {
		if (page.dirty && (page.page != currentPage || page.index == 255)) {
			FlashErasePage(page.page);
			page.index = 255;
			page.dirty = false;
		}
	}
	std::sort(pages.begin(), pages.end(), [](const CfgPage& l, const CfgPage& r) { return l.page < r.page; });

	// Locate latest (active) config block
	uint32_t pos = 0;
	while (pos <= flashPageSize - settingsSize) {
		if (*(flashConfigAddr + pos / 4) == *(uint32_t*)ConfigHeader) {
			currentSettingsOffset = pos;
			pos += settingsSize;
		} else {
			break;			// Either reached the end of the page or found the latest valid config block
		}
	}

	if (currentSettingsOffset >= 0) {
		const uint8_t* flashConfig = reinterpret_cast<uint8_t*>(flashConfigAddr) + currentSettingsOffset;
		uint32_t configPos = headerSize;		// Position in buffer to retrieve settings from

		// Restore settings
		for (auto saver : configSavers) {
			memcpy(saver->settingsAddress, &flashConfig[configPos], saver->settingsSize);
			if (saver->validateSettings != nullptr) {
				saver->validateSettings();
			}
			configPos += saver->settingsSize;
		}
	}
}
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

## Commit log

2024-06-08 Started Panel Layout
    [Uncertain_Times_Panel.kicad_pcb]
2024-06-09 Reduced Panel Size
    [Uncertain_Times_Panel.kicad_pcb]
2024-06-11 More panel layout
    [Uncertain_Times_Panel.kicad_pcb]
2024-06-12 First draft panel layout
    [Uncertain_Times_Panel.kicad_pcb]
2024-06-13 Started to prepare Component schematic
    [Uncertain_Times_Components.kicad_pcb, Uncertain_Times_Components.kicad_sch, Uncertain_Times_Panel.kicad_pcb]
2024-06-13 Schematic Updates
    [Uncertain_Times_Components.kicad_sch]
2024-06-14 Added logo and LEDs to panel
    [Uncertain_Times_Panel.kicad_pcb]
2024-06-14 First draft of schematic
    [Uncertain_Times_Components.kicad_sch, Uncertain_Times_Panel.kicad_pcb]
2024-06-14 Started routing components
    [Uncertain_Times_Components.kicad_pcb, Uncertain_Times_Components.kicad_sch]
2024-06-15 Signal Routing done
    [Uncertain_Times_Components.kicad_pcb, Uncertain_Times_Components.kicad_sch]
2024-06-15 Updated file names
    [Sinosaur_Components.kicad_pcb, Sinosaur_Components.kicad_sch, Sinosaur_Panel.kicad_pcb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]
2024-06-15 Started laying out control board
    [Sinosaur_Controls.kicad_pcb, Sinosaur_Controls.kicad_sch, Sinosaur_Panel.kicad_pcb]
2024-06-15 Started control layout
    [Sinosaur_Components.kicad_sch, Sinosaur_Controls.kicad_pcb, Sinosaur_Controls.kicad_sch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]
2024-06-16 Control PCB wiring
    [Sinosaur_Components.kicad_pcb, Sinosaur_Components.kicad_sch, Sinosaur_Controls.kicad_pcb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]
2024-06-16 Updates to LEDs
    [Sinosaur_Components.kicad_pcb, Sinosaur_Components.kicad_sch, Sinosaur_Controls.kicad_pcb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]
2024-06-18 Gerber production
    [Sinosaur_Components-B_Cu.gbr, Sinosaur_Components-B_Mask.gbr, Sinosaur_Components-B_Paste.gbr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]
2024-06-18 Gerber production for v1
    [Sinosaur_Components-B_Cu.gbr, Sinosaur_Components-B_Mask.gbr, Sinosaur_Components-B_Paste.gbr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]
2024-06-26 Fixed issue with mask on panel pcb
    [Sinosaur_Panel-B_Cu.gbr, Sinosaur_Panel-B_Mask.gbr, Sinosaur_Panel-B_Silkscreen.gbr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]
2024-06-28 Hardware working; started adding modulation code
    [Sinosaur_Components.kicad_sch, Sinosaur_Controls.kicad_sch]
2024-07-03 Started adding swell and ramp functions
    [Sinosaur_Controls.kicad_sch]
2024-07-07 Tweaking rates; ordered new panels
    [Sinosaur_Panel-B_Cu.gbr, Sinosaur_Panel-B_Mask.gbr, Sinosaur_Panel-B_Silkscreen.gbr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]
2024-07-07 Modified envelope scaling and LEDs
2024-07-08 Ramp and swell pots exponentially scaled for better control at low values
    [Sinosaur_Panel.kicad_pcb]
2024-07-09 Added REadme; code cleanup
    [Sinosaur_Components.kicad_sch, Sinosaur_Controls.kicad_sch]
